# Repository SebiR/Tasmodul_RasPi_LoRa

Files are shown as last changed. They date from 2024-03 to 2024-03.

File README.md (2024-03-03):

# Tasmodul Raspberry Pi + LoRa Concentrator
A 100x100mm "Tasmodul" PCB for a Raspberry Pi with the option to populate a LoRaWAN mini PCIe card to work as a LoraWAN gateway

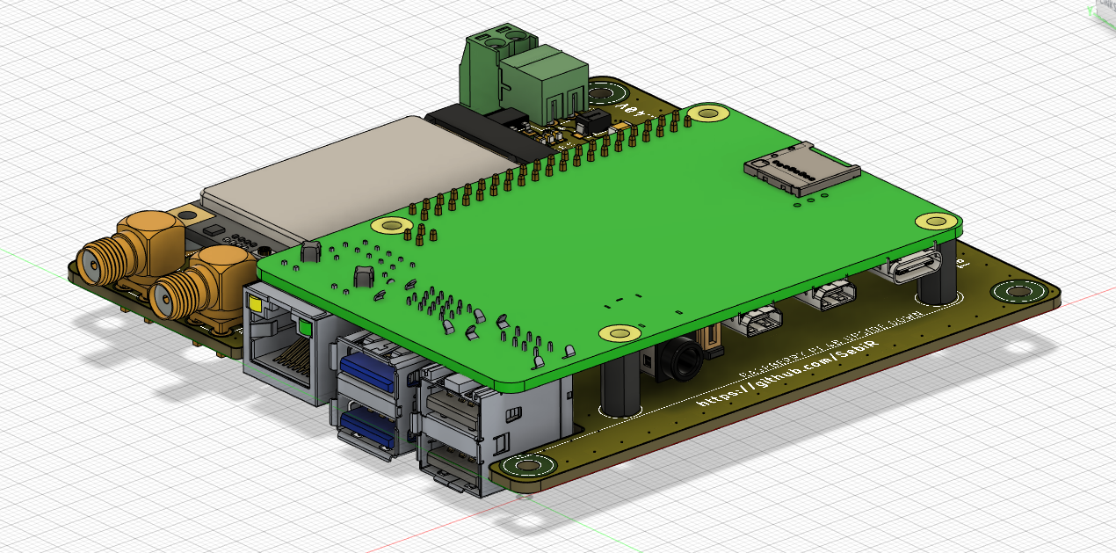
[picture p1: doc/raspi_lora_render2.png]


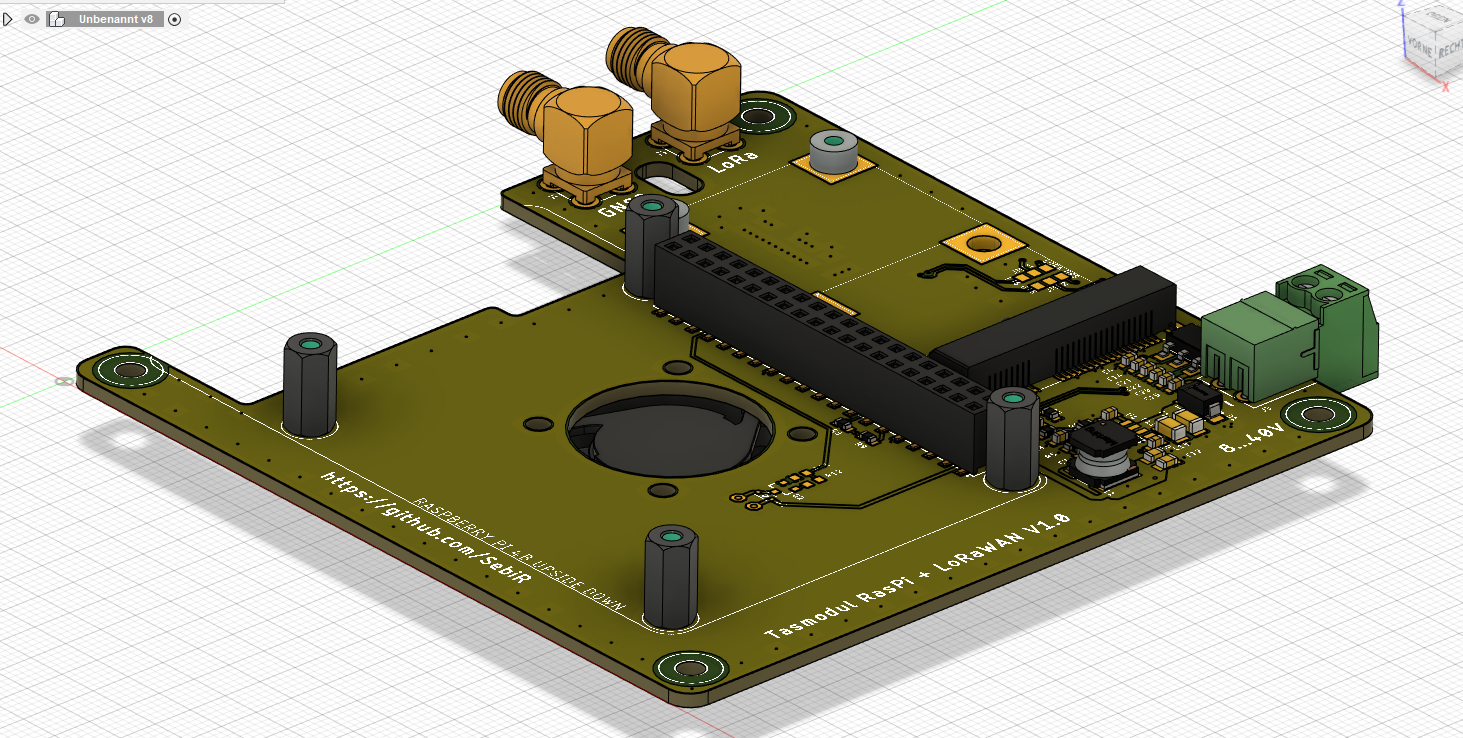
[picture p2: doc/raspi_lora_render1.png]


## Features
* Wide inpult voltage range from 8 to 40V
* Mini-PCIe Slot for LoraWAN concentrator modules like the Seeed WM1302 or the RAK2287
* Optional Quectel L76 GPS module
* Optional small fan controlled by the Raspberry Pi
* Ideal for ChirpStack OS

## GPS
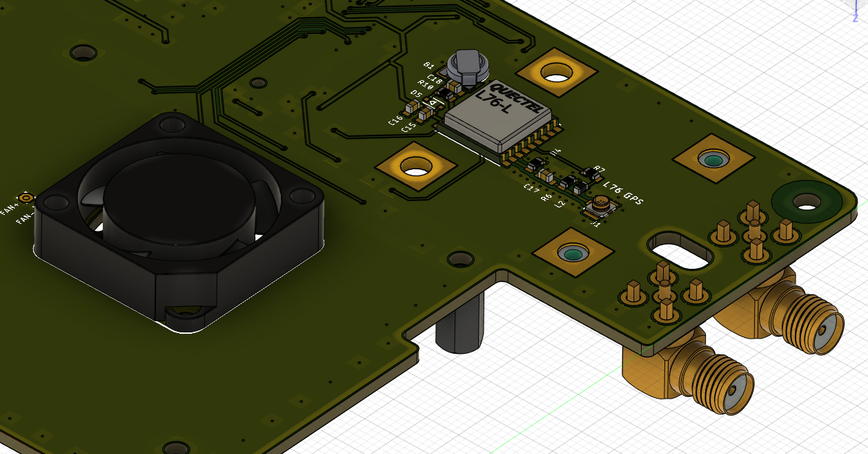
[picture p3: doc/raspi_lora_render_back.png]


## SMA Connectors
Although there's the option to use short U.fl to U.fl connectors, I recommend using those THT SMA connectors with built-in pigtail:

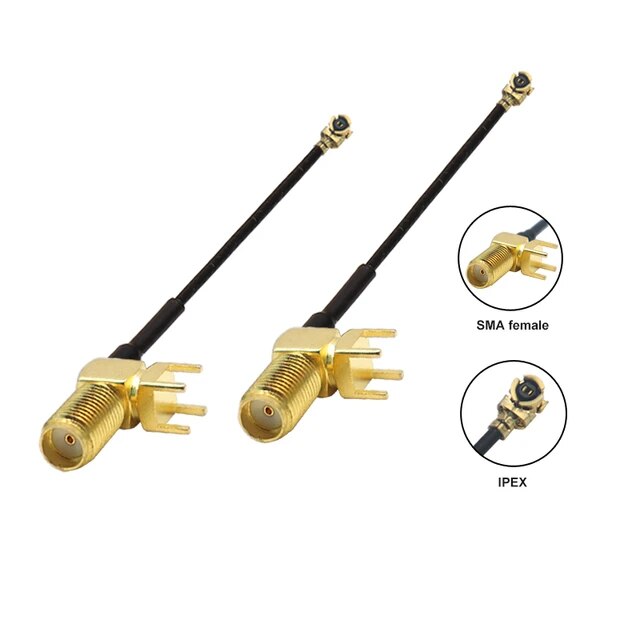
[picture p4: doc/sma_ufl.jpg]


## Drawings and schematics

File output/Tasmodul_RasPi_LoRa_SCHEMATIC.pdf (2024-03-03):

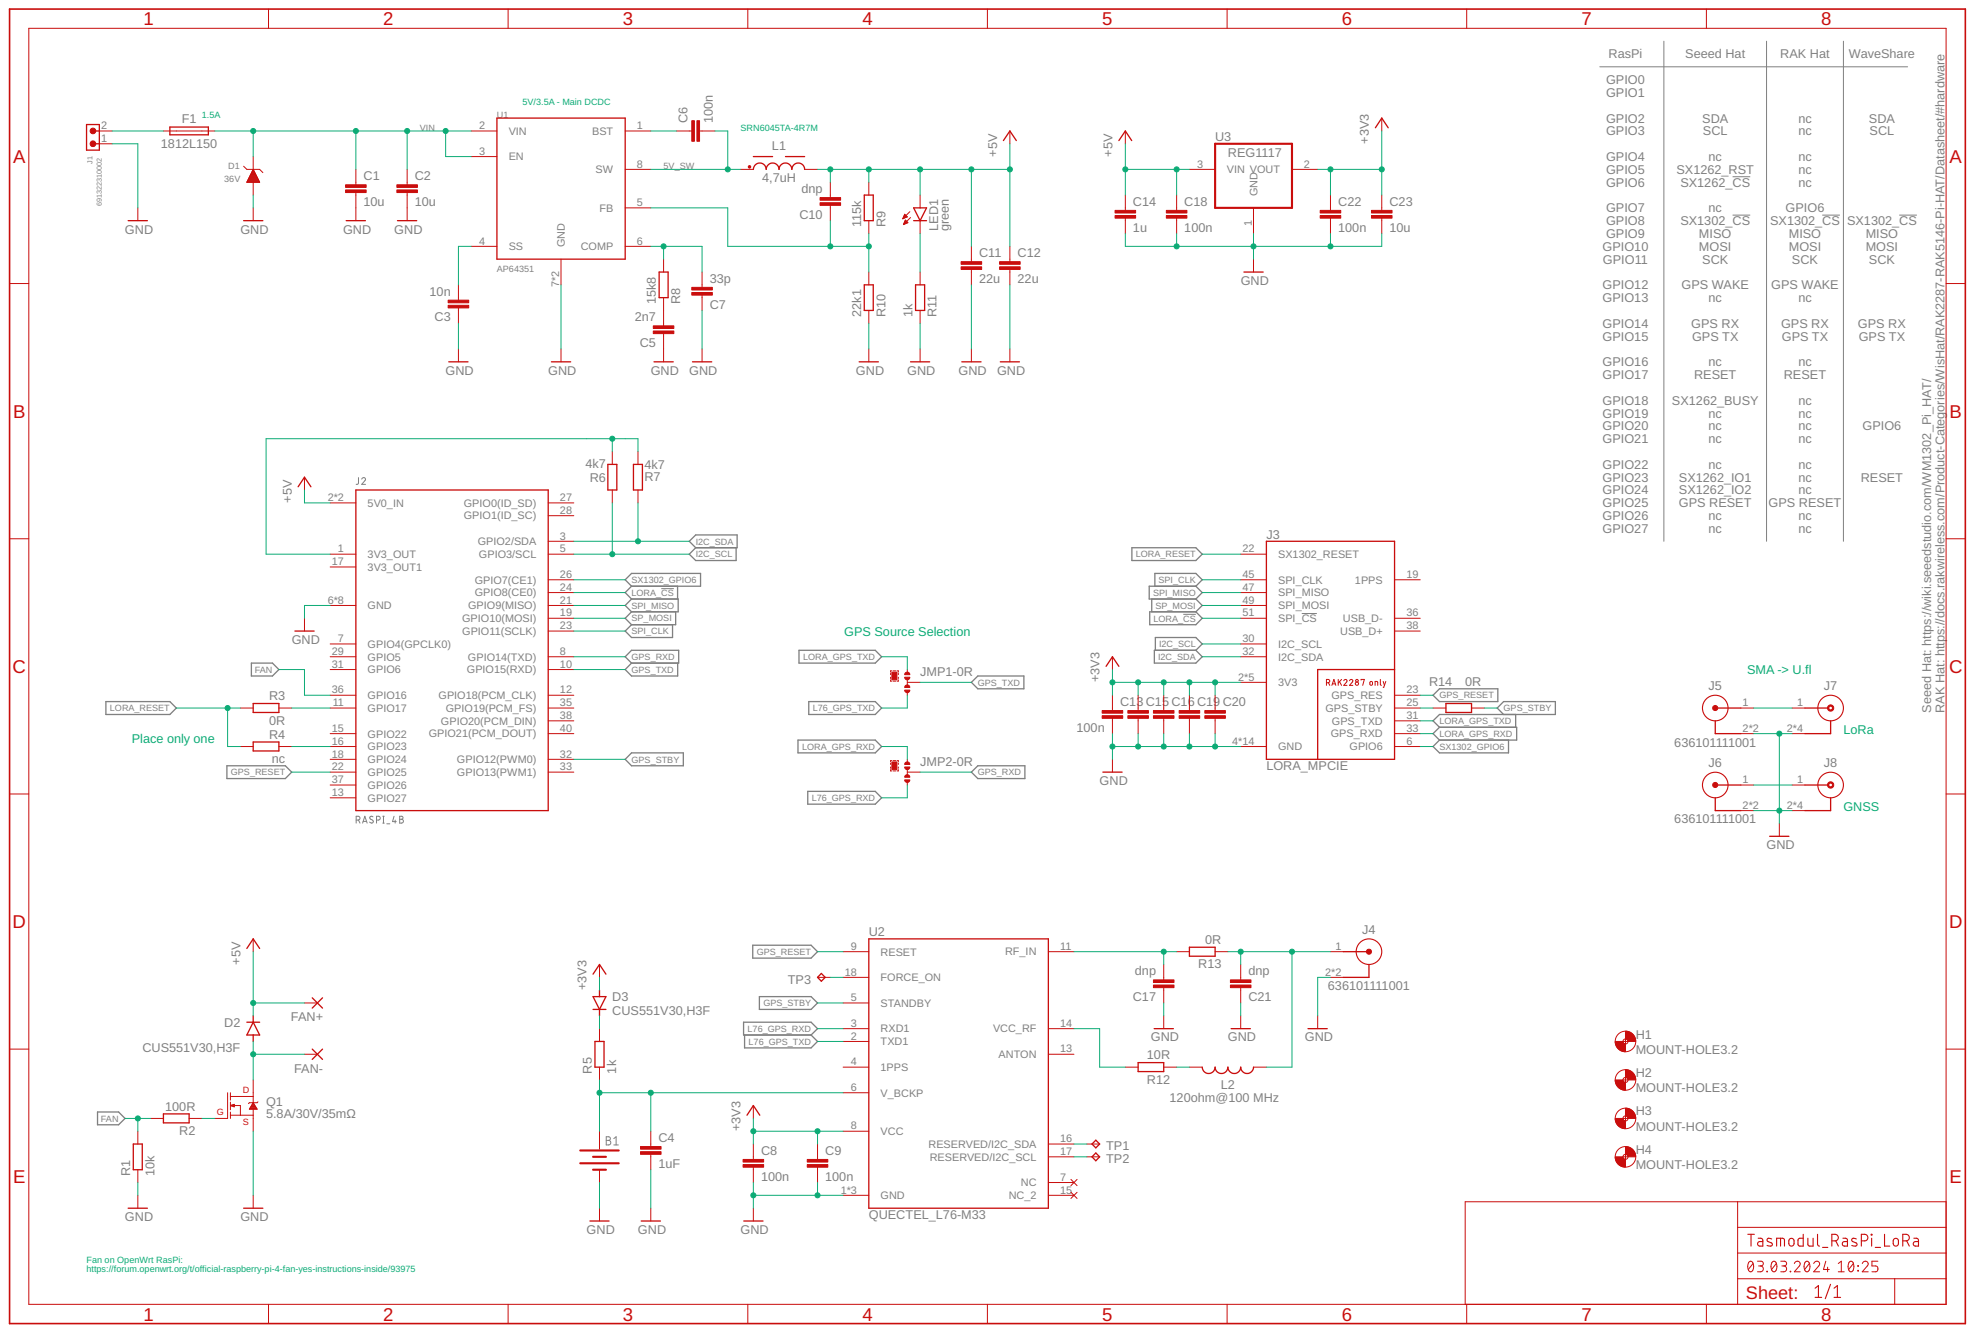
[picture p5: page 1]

M1302_Pi_HAT/ RAK Hat: https:/ docs.rakwireless.com/Product-Categories/WisHat/RAK2287-RAK5146-Pi-HAT/Datasheet/#hardware

Seeed Hat: https:/ wiki.seeedstudio.com/W

Fan on OpenWrt RasPi: https://forum.openwrt.org/t/official-raspberry-pi-4-fan-yes-instructions-inside/93975

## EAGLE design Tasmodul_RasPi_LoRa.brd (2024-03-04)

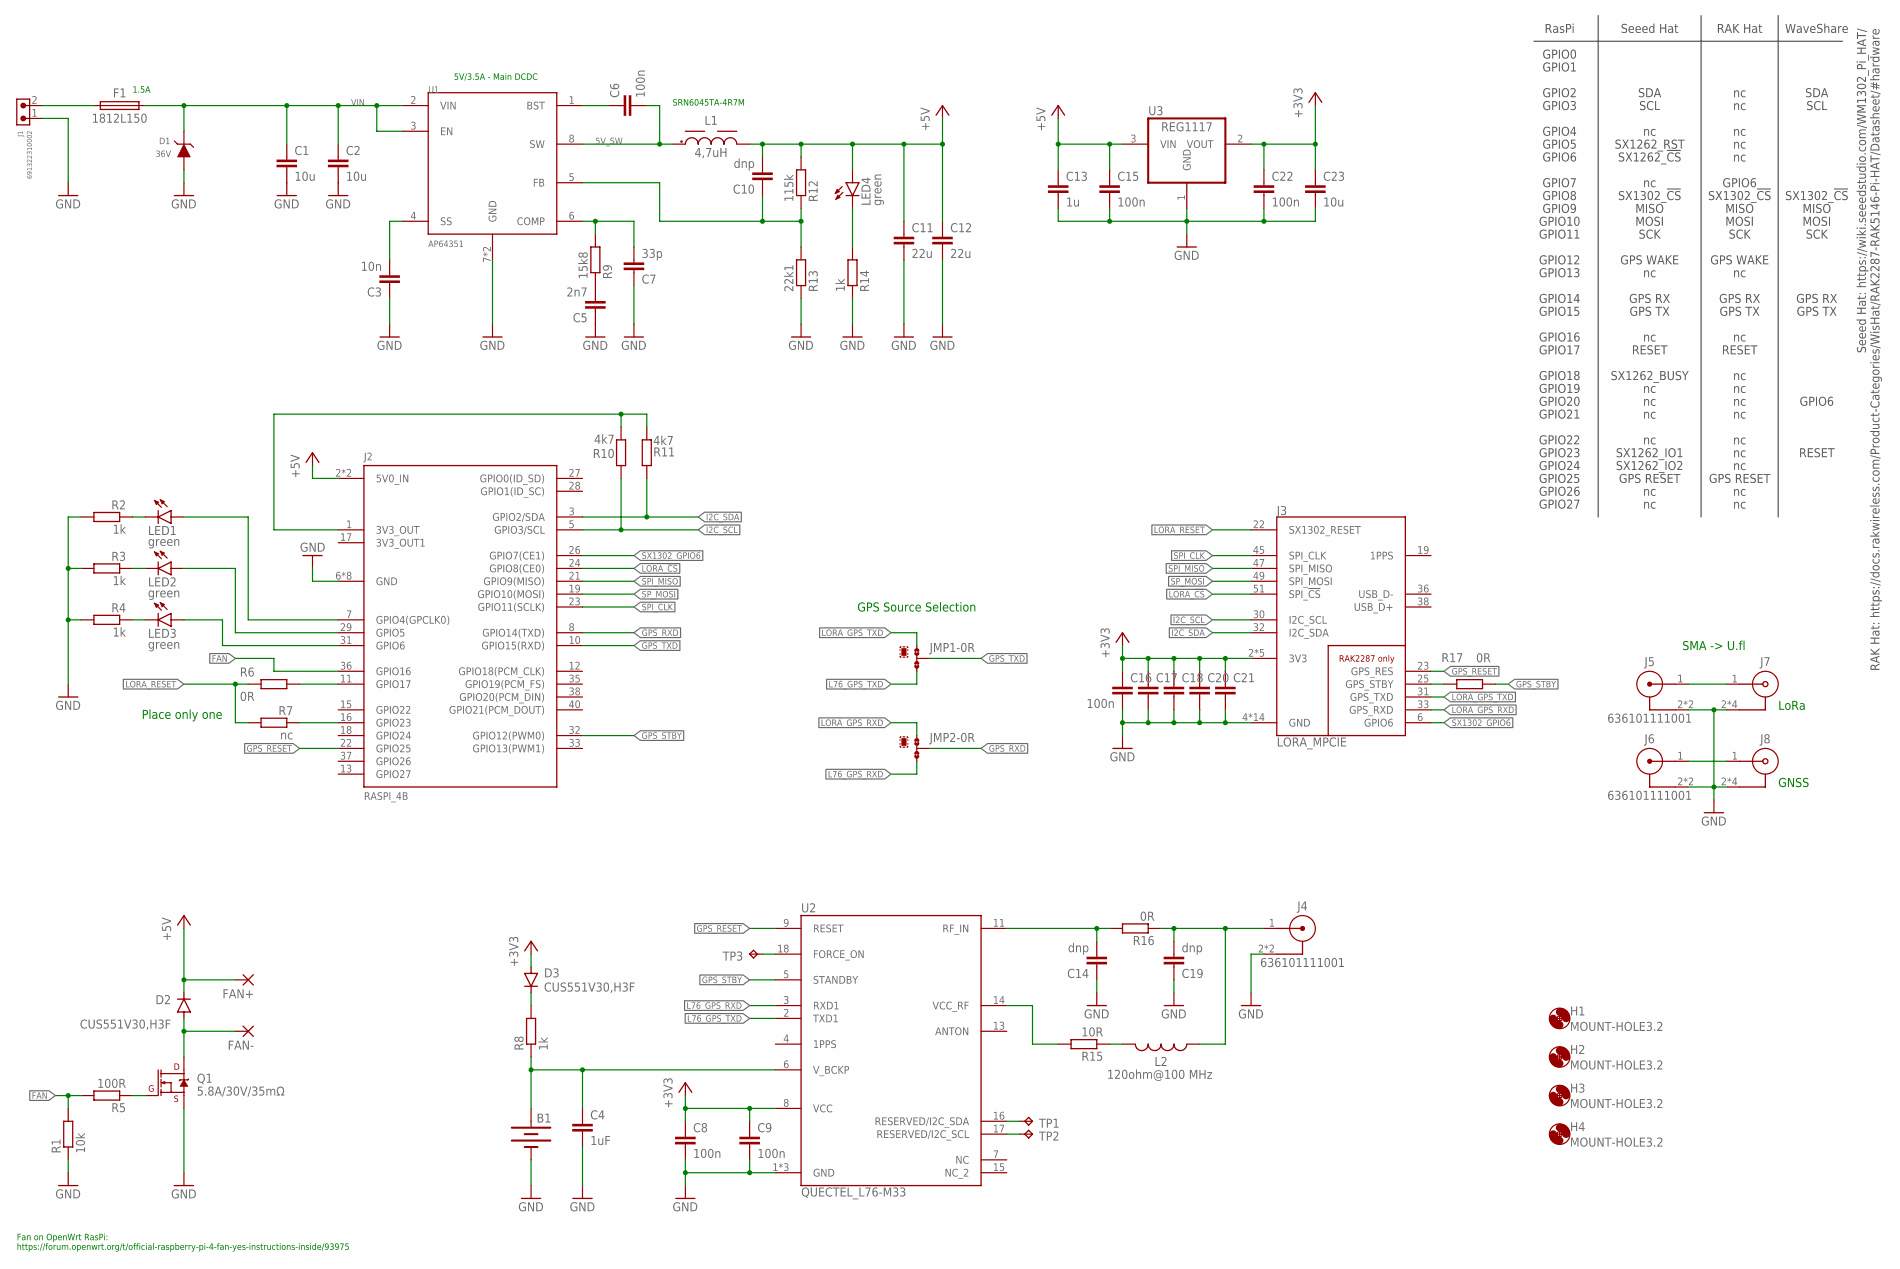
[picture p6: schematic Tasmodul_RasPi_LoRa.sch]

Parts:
B1: 6.8MM_COIN_CELL; ML414H_IV01E
C1, C2: 10u; C1206
C3: 10n; C0603
C4: 1uF; C0603
C5: 2n7; C0603
C6, C8, C9, C15, C16, C17, C18, C20, C21, C22: 100n; C0603
C7: 33p; C0603
C10, C14, C19: dnp; C0603
C11, C12: 22u; C0805
C13: 1u; C0603
C23: 10u; C0603
D1: 36V; WE-TVSP_DO-214AC_UNIDIRECTIONAL
D2, D3: CUS551V30,H3F; SOD323-R
F1: 1812L150; FUSC4532X125
FAN+: 1,6/0,8
FAN-: 1,6/0,8
H1, H2, H3, H4: MOUNT-HOLE3.2; 3,2
J1: 691322310002
J2: RASPI_4B; RASPI_4B_FLIPPED_SMD
J3: LORA_MPCIE; MINI_PCIE_CONNECTOR_5.2H
J4, J5, J6: 636101111001
J7, J8: 60311002111526
JMP1, JMP2: 0R-JUMPA; A0R-JMP
L1: 4,7uH; WE-LQS_6045
L2: 120ohm@100 MHz; WE-CBF_0603_W2.2
LED1, LED2, LED3, LED4: green; CHIPLED_0603
Q1: 5.8A/30V/35mΩ; SOT23-3
R1: 10k; R0603
R2, R3, R4, R8, R14: 1k; R0603
R5: 100R; R0603
R6, R16, R17: 0R; R0603
R7: nc; R0603
R9: 15k8; R0603
R10, R11: 4k7; R0603
R12: 115k; R0603
R13: 22k1; R0603
R15: 10R; R0603
TP1, TP2, TP3: TPTP15R; TP15R
U1: AP64351; SOIC8-EP
U2: QUECTEL_L76-M33; L76_QWS
U3: REG1117; SOT223

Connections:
5V_SW: C6.2, L1.1, U1.8 (SW)
+3V3: C8.1, C9.1, C16.1, C17.1, C18.1, C20.1, C21.1, C22.1, C23.1, D3.A, J3.2 (3V3), J3.24 (3V3), J3.39 (3V3), J3.41 (3V3), J3.52 (3V3), U2.8 (VCC), U3.2 (VOUT)
+5V: C10.2, C11.1, C12.1, C13.1, C15.1, D2.C, FAN+.1, J2.2 (5V0_IN), J2.4 (5V0_IN), L1.2, LED4.A, R12.2, U3.3 (VIN)
FAN: J2.36 (GPIO16), R1.2, R5.2
GND: B1.-, C1.2, C2.2, C3.1, C4.2, C5.1, C7.1, C8.2, C9.2, C11.2, C12.2, C13.2, C14.1, C15.2, C16.2, C17.2, C18.2, C19.1, C20.2, C21.2, C22.2, C23.2, D1.2 (A), J1.1, J2.6 (GND), J2.9 (GND), J2.14 (GND), J2.20 (GND), J2.25 (GND), J2.30 (GND), J2.34 (GND), J2.39 (GND), J3.4 (GND), J3.9 (GND), J3.15 (GND), J3.18 (GND), J3.21 (GND), J3.26 (GND), J3.27 (GND), J3.29 (GND), J3.34 (GND), J3.35 (GND), J3.37 (GND), J3.40 (GND), J3.43 (GND), J3.50 (GND), J4.2, J4.3 (2), J5.2, J5.3 (2), J6.2, J6.3 (2), J7.2, J7.3 (2), J7.4 (2), J7.5 (2), J8.2, J8.3 (2), J8.4 (2), J8.5 (2), Q1.2 (S), R1.1, R2.2, R3.2, R4.2, R13.1, R14.1, U1.7 (GND), U1.9 (GND), U2.1 (GND), U2.10 (GND), U2.12 (GND), U3.1 (GND)
GPS_RESET: J2.22 (GPIO25), J3.23 (GPS_RES), U2.9 (RESET)
GPS_RXD: J2.8 (GPIO14(TXD)), JMP2.2
GPS_STBY: J2.32 (GPIO12(PWM0)), R17.1, U2.5 (STANDBY)
GPS_TXD: J2.10 (GPIO15(RXD)), JMP1.2
HF_GNSS: J6.1, J8.1
HF_LORA: J5.1, J7.1
I2C_SCL: J2.5 (GPIO3/SCL), J3.30 (I2C_SCL), R10.1
I2C_SDA: J2.3 (GPIO2/SDA), J3.32 (I2C_SDA), R11.1
L76_GPS_RXD: JMP2.3, U2.3 (RXD1)
L76_GPS_TXD: JMP1.3, U2.2 (TXD1)
LORA_!CS: J2.24 (GPIO8(CE0)), J3.51 (SPI_!CS)
LORA_GPS_RXD: J3.33 (GPS_RXD), JMP2.1
LORA_GPS_TXD: J3.31 (GPS_TXD), JMP1.1
LORA_RESET: J3.22 (SX1302_RESET), R6.2, R7.2
unnamed: J2.16 (GPIO23), R7.1
unnamed: C3.2, U1.4 (SS)
unnamed: J2.11 (GPIO17), R6.1
unnamed: L2.2, R15.1
unnamed: C6.1, U1.1 (BST)
unnamed: C10.1, R12.1, R13.2, U1.5 (FB)
unnamed: LED4.C, R14.2
unnamed: D3.C, R8.2
unnamed: Q1.1 (G), R5.1
unnamed: R15.2, U2.14 (VCC_RF)
unnamed: C5.2, R9.1
unnamed: C7.2, R9.2, U1.6 (COMP)
unnamed: J2.1 (3V3_OUT), R10.2, R11.2
unnamed: D2.A, FAN-.1, Q1.3 (D)
unnamed: F1.1, J1.2
unnamed: TP1.TP, U2.16 (RESERVED/I2C_SDA)
unnamed: TP2.TP, U2.17 (RESERVED/I2C_SCL)
unnamed: TP3.TP, U2.18 (FORCE_ON)
unnamed: J3.25 (GPS_STBY), R17.2
unnamed: LED1.C, R2.1
unnamed: LED2.C, R3.1
unnamed: LED3.C, R4.1
unnamed: J2.7 (GPIO4(GPCLK0)), LED1.A
unnamed: J2.29 (GPIO5), LED2.A
unnamed: J2.31 (GPIO6), LED3.A
RF_CON: C19.2, J4.1, L2.1, R16.1
RF_MATCHED: C14.2, R16.2, U2.11 (RF_IN)
SPI_CLK: J2.23 (GPIO11(SCLK)), J3.45 (SPI_CLK)
SPI_MISO: J2.21 (GPIO9(MISO)), J3.47 (SPI_MISO)
SP_MOSI: J2.19 (GPIO10(MOSI)), J3.49 (SPI_MOSI)
SX1302_GPIO6: J2.26 (GPIO7(CE1)), J3.6 (GPIO6)
VBAT: B1.+, C4.1, R8.1, U2.6 (V_BCKP)
VIN: C1.1, C2.1, D1.1 (C), F1.2, U1.2 (VIN), U1.3 (EN)

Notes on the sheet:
GPIO0
GPIO1
GPIO2
GPIO3
GPIO4
GPIO5
GPIO6
GPIO7
GPIO8
GPIO9
GPIO10
GPIO11
GPIO12
GPIO13
GPIO14
GPIO15
GPIO16
GPIO17
GPIO18
GPIO19
GPIO20
GPIO21
GPIO22
GPIO23
GPIO24
GPIO25
GPIO26
GPIO27
Seeed Hat
RasPi
RAK Hat
SCL
SDA
GPS RX
GPS TX
RESET
SX1262_BUSY
MOSI
MISO
SCK

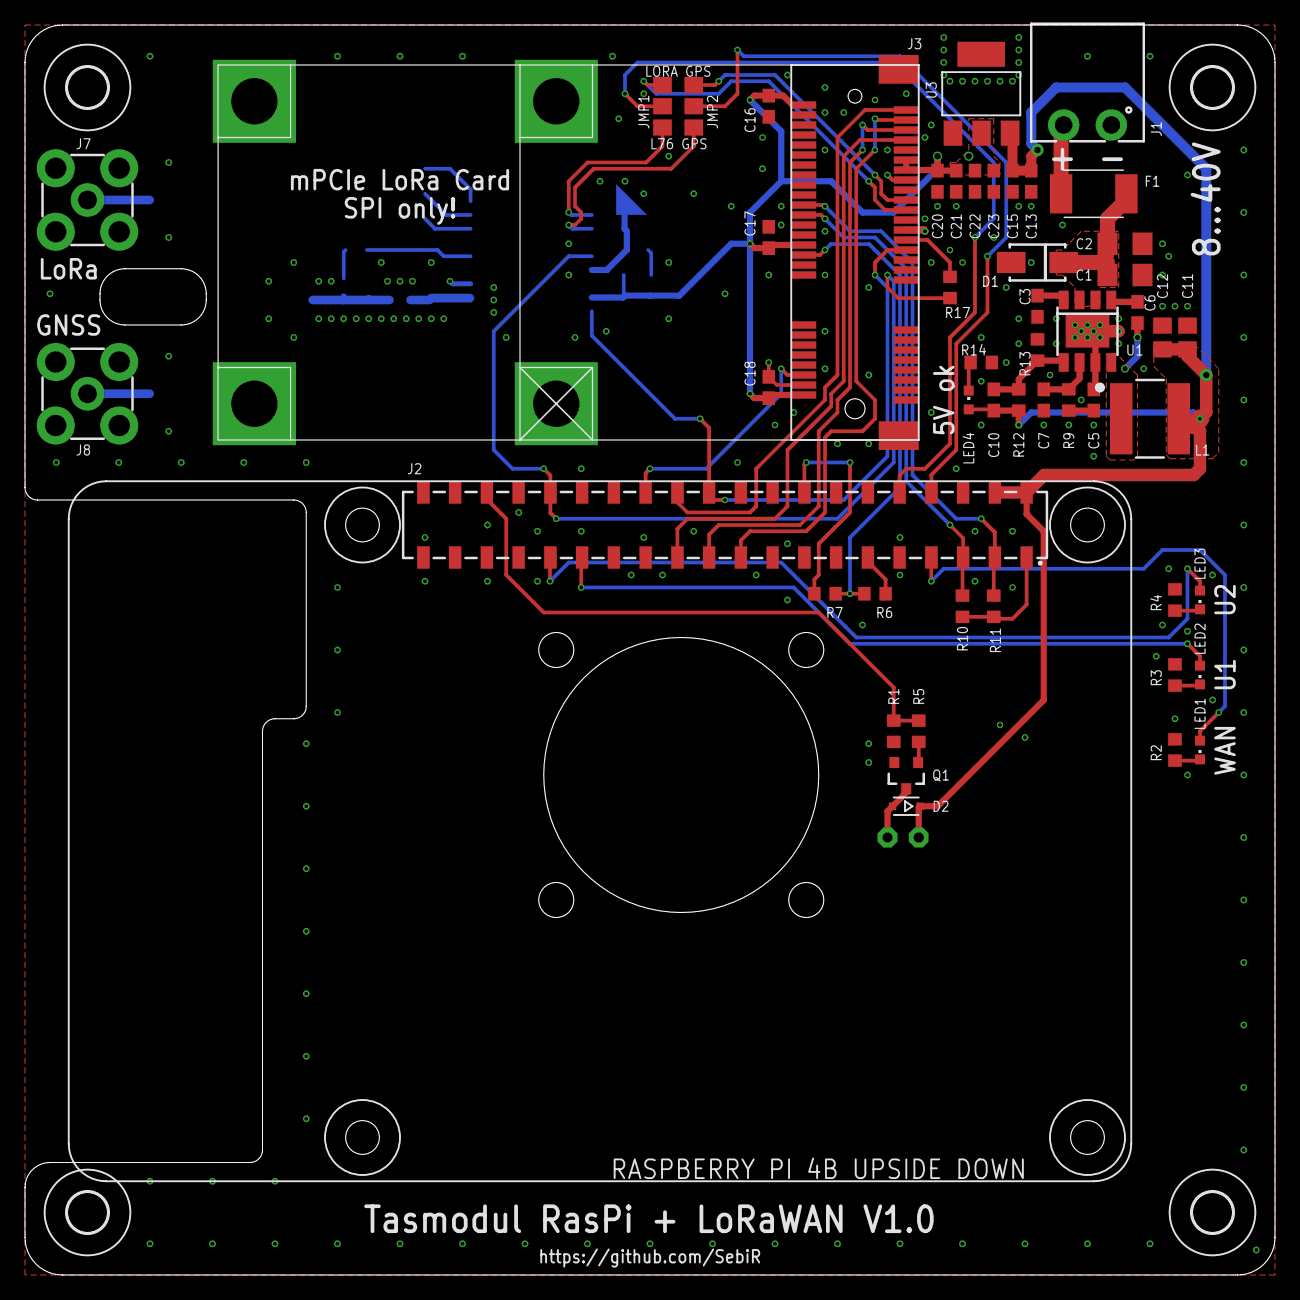
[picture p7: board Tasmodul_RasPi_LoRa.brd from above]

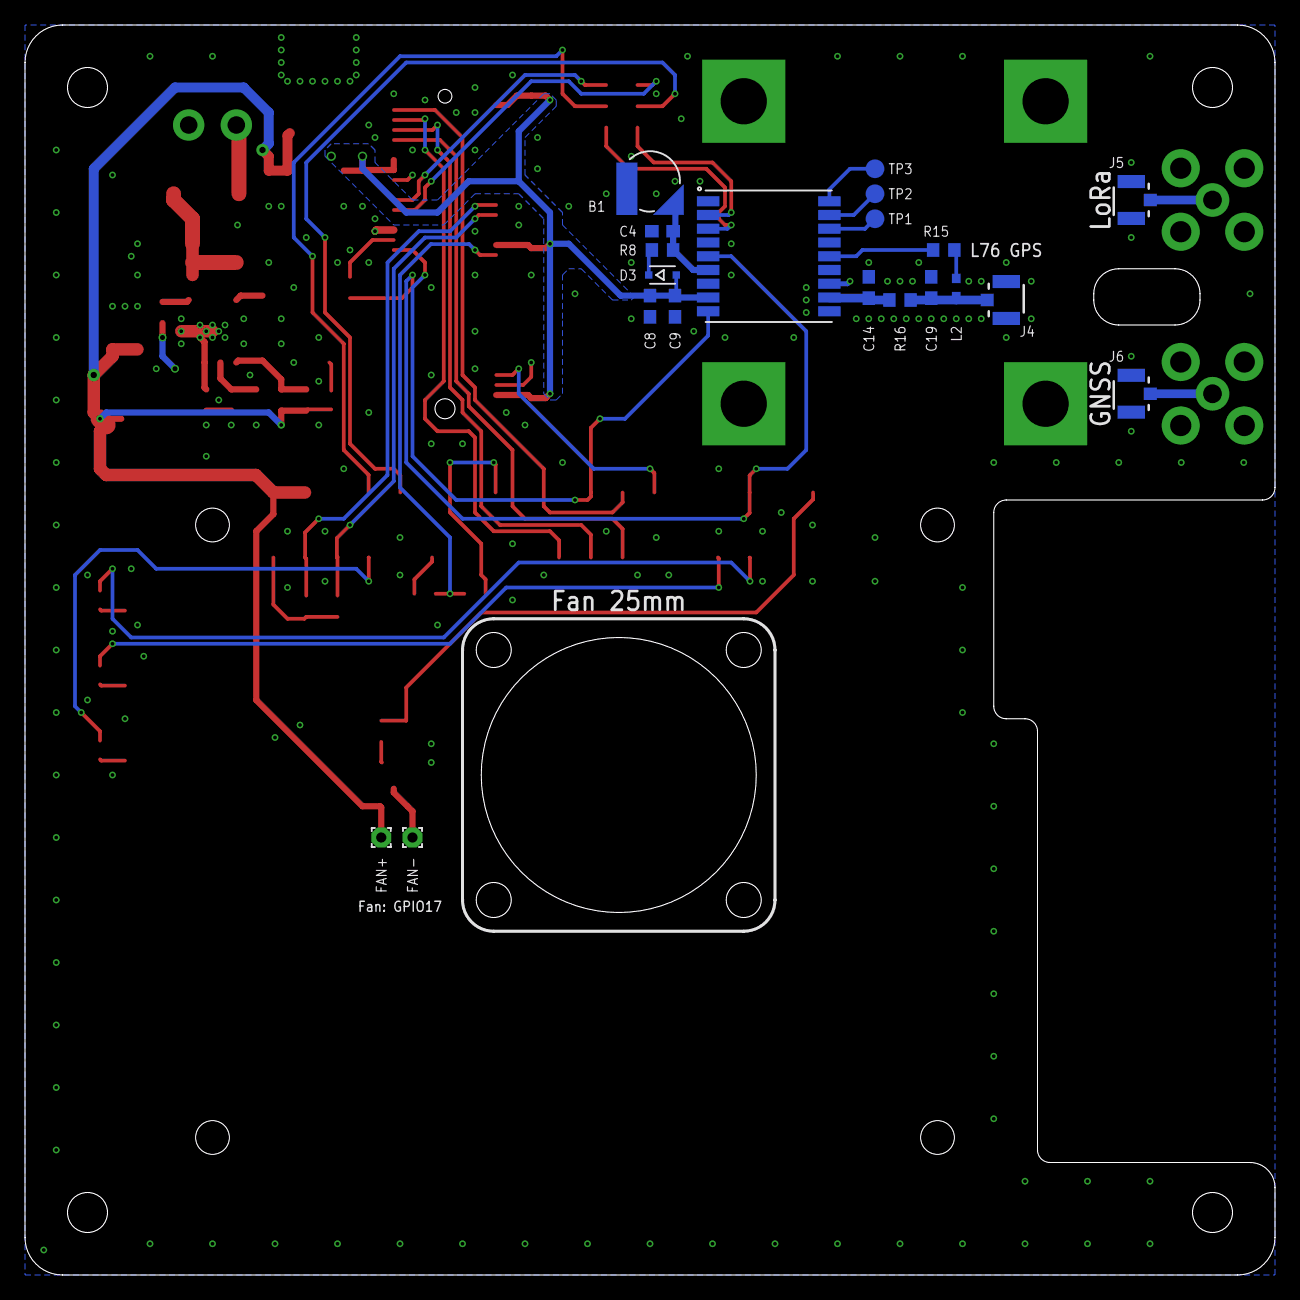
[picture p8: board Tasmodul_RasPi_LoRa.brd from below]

Board: 2 copper layers, 100.0 x 100.0 mm, 75 parts (21 on the bottom side), 52 nets.

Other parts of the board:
U$1: FAN_25MM

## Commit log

2024-03-02 * Added more description to the schematic * Added more silk screen information to the PCB * Added U.fl connectors for the SMA connectors as a backup
    [Tasmodul_RasPi_LoRa.brd, Tasmodul_RasPi_LoRa.sch]
2024-03-03 * Added multifuse to power input * Added I2C pullup resistors * Added test points to unused GPS module pins * Updated README.md
    [Tasmodul_RasPi_LoRa.brd, Tasmodul_RasPi_LoRa.sch]
2024-03-04 * Added 3 status LEDs to the RasPi * Minor Layout tweaks
    [Tasmodul_RasPi_LoRa.brd, Tasmodul_RasPi_LoRa.sch]

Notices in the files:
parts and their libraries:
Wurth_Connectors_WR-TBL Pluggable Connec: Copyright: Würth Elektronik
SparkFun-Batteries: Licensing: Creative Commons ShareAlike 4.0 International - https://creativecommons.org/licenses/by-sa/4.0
